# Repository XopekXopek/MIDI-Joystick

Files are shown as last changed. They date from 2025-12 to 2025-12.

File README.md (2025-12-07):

The DIY MIDI Joystick project is a custom-built controller originaly designed for Elektron Monomachine (c).  
Joystick can be used for controlling other hardware and software music instruments, effects, and adding unique motion-based input to any MIDI-compatible setup.

Built around an Arduino microcontroller, the device supports multiple operational modes, channel selection, 
button inputs, and precise analog readings from X/Y joystick axes. 

It communicates through USB or classic 5-pin MIDI DIN input/output and supports MIDI IN → MIDI OUT (thru) forwarding.

Features:

Pitch Bend on X-axis
Split CC control (CC1 + CC2) on Y-axis
MIDI channel selection
Axis swapping (X ↔ Y)
Full calibration system
EEPROM storage settings
MIDI Thru
LED status indication

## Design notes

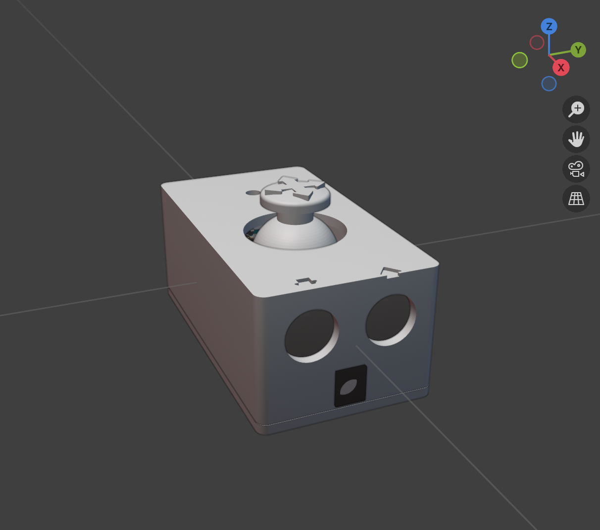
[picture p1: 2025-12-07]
Enclosure/3D overview.png

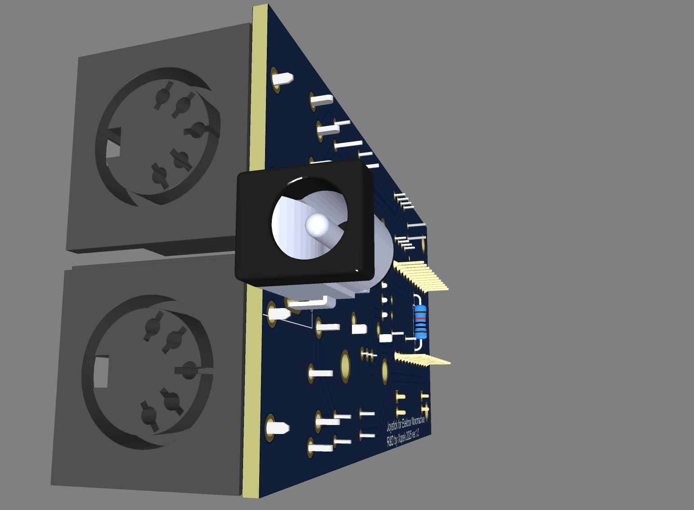
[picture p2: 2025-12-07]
PCB&Schematic/PCB_3.png

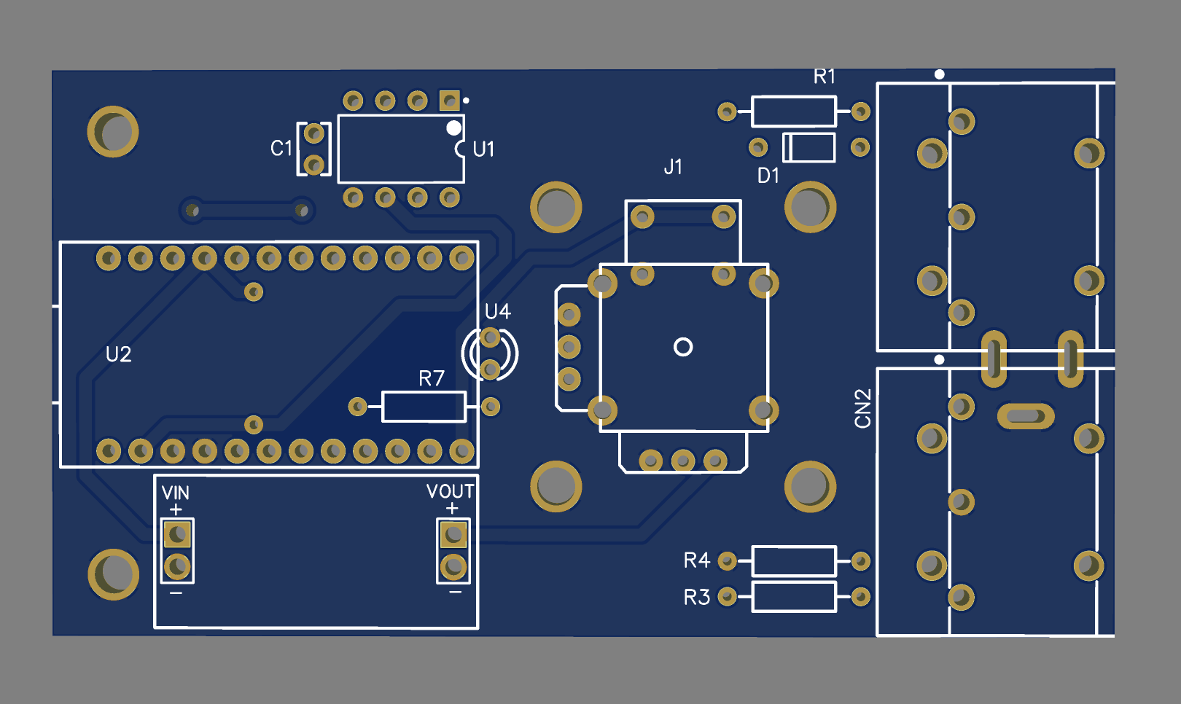
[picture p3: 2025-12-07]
PCB&Schematic/PCB_2.png

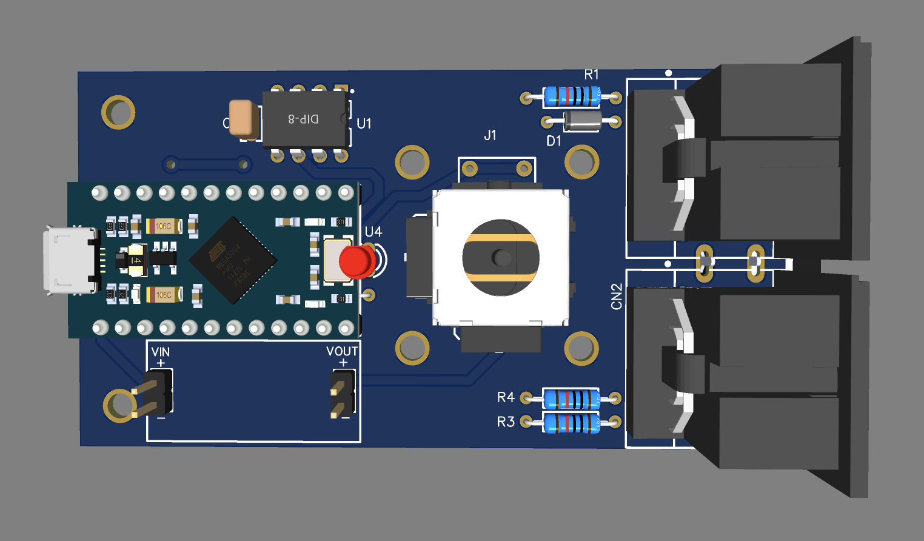
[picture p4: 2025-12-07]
PCB&Schematic/PCB_1.png

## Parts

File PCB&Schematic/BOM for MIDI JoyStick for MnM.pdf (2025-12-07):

BOM for Elektron Monomachine (c) MIDI Joystick ver. 1.0

ID | Name | Designator | Quantity | Manufacturer Part
1 | DIN-5 MIDI INPUT/OUTPUT | CN1, CN2 | 2 | DIN-504-M10
3 | 1N4148 | D1 | 1 | 1N4148
4 | DC Jack socket 5.5 X 2.5 mm | DC1 | 1 | DCS-005
5 | 220R | R1,R3,R4 | 3 | MF 1/4W-220Ω±1%
6 | 1K | R2,R7 | 2 | MF 1/4W-1KΩ±1%
7 | 6N137 | U1 | 1 | HT-6N137
8 | ARDUINO PRO MICRO | U2 | 1 | ARDUINO PRO MICRO (USB C or mcroUSB)
9 | LED | U4 | 1 | 5mm
10 | 100nF | C1 | 1 | Metalfilm Cap
11 | Module YL-46 | VIN,VOUT | 1 | AMS1117 3.3V 5.0V DC-DC Step down Power Supply
12 | Joystick | P1 | 1 | Dualsense PS5/Ginfull with button
13 | DC Y-cable 5.5 X 2.5 mm | - | 1 | DC Y-cable 5.5 X 2.5 mm

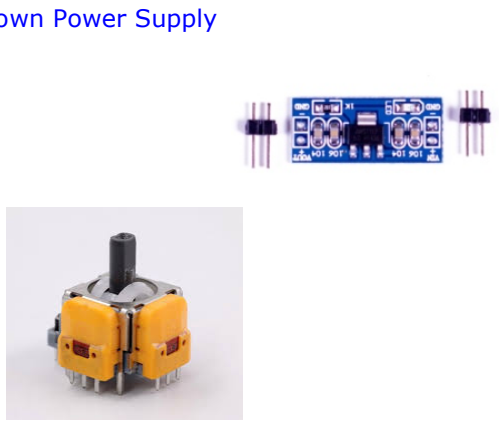
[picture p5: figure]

AMS1117 3.3V 5.0V DC-DC Step down Power Supply

Dualsense PS5/Ginfull with button

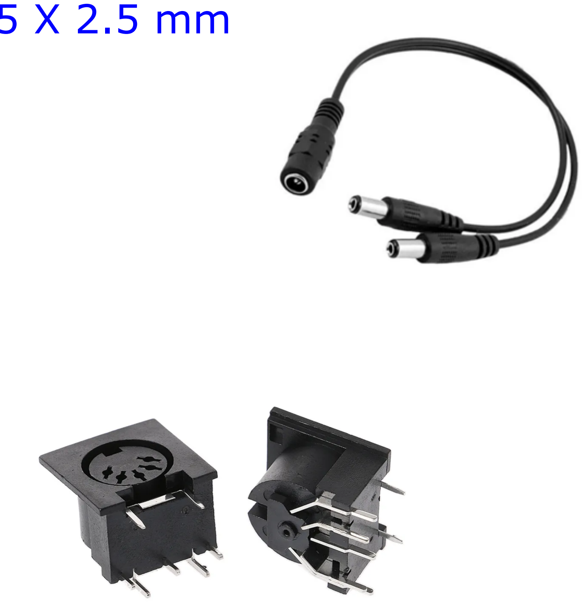
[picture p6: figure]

DC Y-cable 5.5 X 2.5 mm

DIN-504-M10

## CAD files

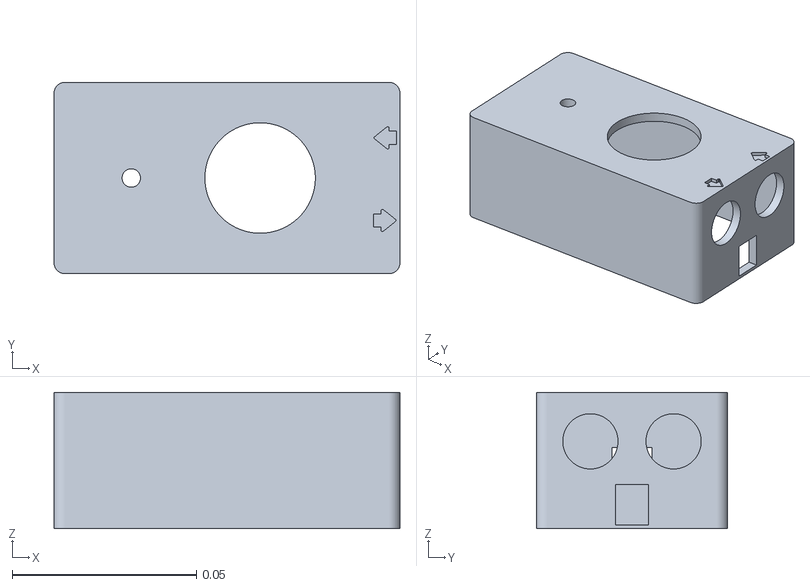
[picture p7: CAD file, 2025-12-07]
Enclosure/Enclosure_main.stl
0.094 x 0.052 x 0.037

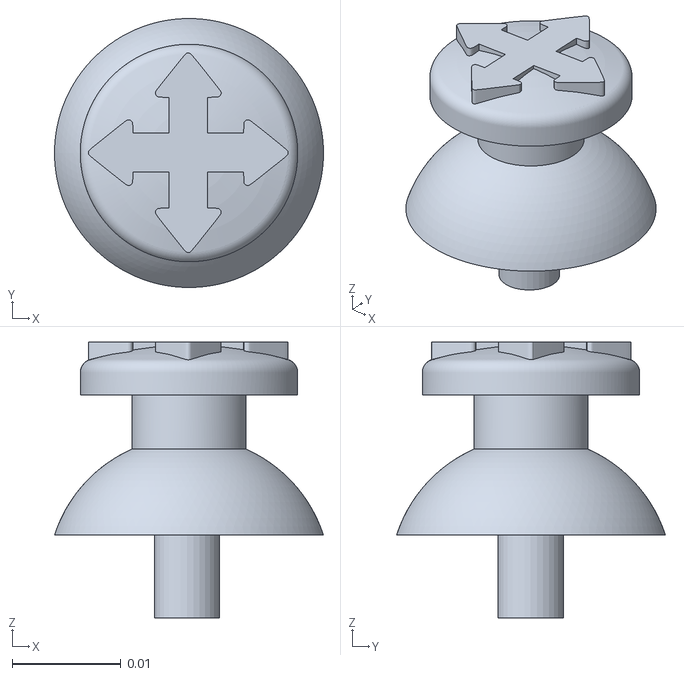
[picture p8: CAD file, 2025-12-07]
Enclosure/Joystick_cap.stl
0.0247 x 0.0247 x 0.0254

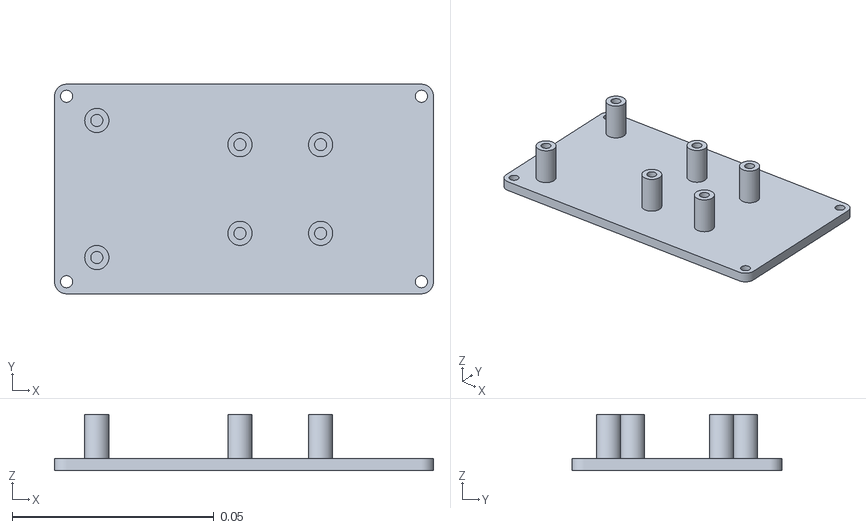
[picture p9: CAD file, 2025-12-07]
Enclosure/bottom_cover.stl
0.094 x 0.052 x 0.014

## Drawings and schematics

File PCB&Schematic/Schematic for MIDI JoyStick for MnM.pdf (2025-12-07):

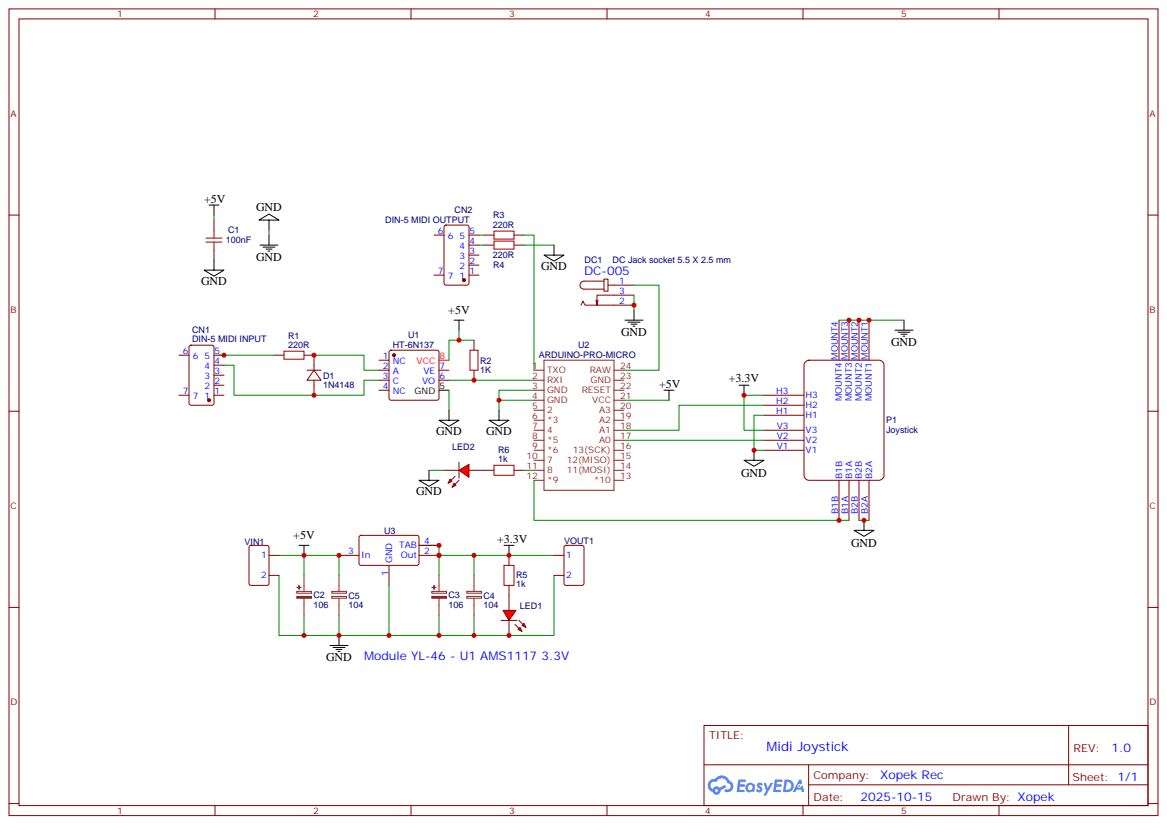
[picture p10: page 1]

DC1 DC Jack socket 5.5 X 2.5 mm

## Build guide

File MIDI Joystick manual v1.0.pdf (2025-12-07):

# 📘 MIDI Joystick – User Manual v.1.0

## ⚙ Overview

This device is a MIDI controller based on an analog joystick and a single button.
It communicates through a classic 5-pin MIDI DIN output and supports MIDI IN → MIDI OUT (thru) forwarding.

Features:

- Pitch Bend on X-axis
- Split CC control (CC1 + CC2) on Y-axis
- MIDI channel selection
- Axis swapping (X ↔ Y)
- Full calibration system
- EEPROM storage
- MIDI Thru
- LED status indication

# 🎮 Joystick Functions

## X-Axis → Pitch Bend

- Left = −8192
- Center = 0
- Right = +8191
- Includes a small deadzone to prevent jitter.

## Y-Axis → Split CC Control (CC1 / CC2)

The Y-axis is divided into two functional halves:

Position | MIDI CC Value Range
Below center (0–63) CC1 | 63 → 0
Above center (65–127) CC2 | 0 → 63

The center point (64) sends no data to avoid unwanted triggering.

# 🔘 Button Functions

The button performs different actions depending on short presses, long presses, and sequences.

## 1⃣Select MIDI Channel (1–16)

Enter MIDI Channel Setup

Hold the button for more than 3 seconds.
The LED blinks 3 times — channel setup mode is active.

Select the channel

Press the button N times:

- 1 press → Channel 1
- 2 presses → Channel 2
- …
- 16 presses → Channel 16

Each press is confirmed by one LED blink.

Confirm the channel

Hold the button for more than 5 seconds.
LED will blink N times — the selected channel. The device returns to normal mode.

## 2⃣ Swap Axes (X ↔ Y)

Perform 5 short presses in a row.
LED blinks 2 times.
Useful if the joystick is mounted sideways or rotated.

## 3⃣ Joystick Calibration Mode

Enter Calibration

Perform 10 short presses in a row.
LED blinks 5 times.

Calibrating

Move the joystick to all edges and corners. The device automatically captures:

- Xmin / Xmax
- Ymin / Ymax

Exit Calibration and Save

Hold the button for more than 5 seconds. LED blinks 3 times — calibration saved.

# 💾 EEPROM Storage

The following parameters are stored permanently:

- Joystick calibration
- MIDI channel
- Axis swap setting

These values remain stored even after powering off.

# 🔌 MIDI IN → MIDI OUT (Thru)

All incoming MIDI DIN messages are automatically forwarded to MIDI OUT:

- Note On / Off
- Control Change
- Pitch Bend
- Channel messages

This allows chaining the joystick controller with other MIDI devices.

# 🔆 LED Indicator Codes

Event | LED Blinks
Enter MIDI channel setup 3
Short press in MIDI setup 1
Confirm MIDI channel | N
Axis swap | 2
Enter calibration | 5
Exit calibration | 3

# 📎 Quick Control Summary

- Hold > 3 sec → MIDI channel setup
- N short presses → Select channel
- Hold > 5 sec → Confirm channel

- 5 short presses → Swap X/Y axes
- 10 short presses → Calibration mode
- Hold > 5 sec (in calibration) → Save calibration

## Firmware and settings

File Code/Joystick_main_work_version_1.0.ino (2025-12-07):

#include <MIDI.h>
#include <EEPROM.h>
#include <elapsedMillis.h>

MIDI_CREATE_DEFAULT_INSTANCE();

enum Mode {
  MODE_PLAY,
  MODE_CHANNEL_SELECT,
  MODE_SENS_SELECT,
  MODE_CALIBRATION
};

Mode currentMode = MODE_PLAY;

const int buttonPin = 2;
const int xPin = A0;
const int yPin = A1;
int midiChannel = 1;
int sensivity = 10;

bool buttonPressed = false;
bool longPress = false;
elapsedMillis buttonTimer;
const unsigned long longPressTime = 600;

int rawCenterX = 512;
int rawCenterY = 512;

int calibrationMinX = 1023;
int calibrationMaxX = 0;
int calibrationMinY = 1023;
int calibrationMaxY = 0;

void saveSettings() {
  EEPROM.update(0, midiChannel);
  EEPROM.update(1, sensivity);
  EEPROM.put(2, rawCenterX);
  EEPROM.put(4, rawCenterY);
}

void loadSettings() {
  midiChannel = EEPROM.read(0);
  sensivity = EEPROM.read(1);
  EEPROM.get(2, rawCenterX);
  EEPROM.get(4, rawCenterY);
  if (midiChannel < 1 || midiChannel > 16) midiChannel = 1;
  if (sensivity < 1 || sensivity > 20) sensivity = 10;
}

void setup() {
  pinMode(buttonPin, INPUT_PULLUP);
  MIDI.begin(MIDI_CHANNEL_OMNI);
  loadSettings();
}

void handleButton() {
  if (!digitalRead(buttonPin)) {
    if (!buttonPressed) {
      buttonPressed = true;
      buttonTimer = 0;
    } else {
      if (buttonTimer > longPressTime && !longPress) {
        longPress = true;
      }
    }
  } else {
    if (buttonPressed) {
      if (longPress) {
        switch (currentMode) {
          case MODE_PLAY:
            currentMode = MODE_CALIBRATION;
            break;
          case MODE_CALIBRATION:
            saveSettings();
            currentMode = MODE_PLAY;
            break;
          default:
            break;
        }
      } else {
        switch (currentMode) {
          case MODE_PLAY:
            currentMode = MODE_CHANNEL_SELECT;
            break;
          case MODE_CHANNEL_SELECT:
            midiChannel++;
            if (midiChannel > 16) midiChannel = 1;
            saveSettings();
            break;
          case MODE_SENS_SELECT:
            sensivity++;
            if (sensivity > 20) sensivity = 1;
            saveSettings();
            break;
          default:
            break;
        }
      }
    }
    buttonPressed = false;
    longPress = false;
  }
}

void handleJoystick() {
  int x = analogRead(xPin);
  int y = analogRead(yPin);
  x = map(x, calibrationMinX, calibrationMaxX, 0, 127);
  y = map(y, calibrationMinY, calibrationMaxY, 0, 127);
  x = constrain(x, 0, 127);
  y = constrain(y, 0, 127);
  MIDI.sendControlChange(1, x, midiChannel);
  MIDI.sendControlChange(2, y, midiChannel);
}

void handleCalibration() {
  int x = analogRead(xPin);
  int y = analogRead(yPin);
  if (x < calibrationMinX) calibrationMinX = x;
  if (x > calibrationMaxX) calibrationMaxX = x;
  if (y < calibrationMinY) calibrationMinY = y;
  if (y > calibrationMaxY) calibrationMaxY = y;
}

void loop() {
  handleButton();
  switch (currentMode) {
    case MODE_PLAY:
      handleJoystick();
      break;
    case MODE_CHANNEL_SELECT:
      break;
    case MODE_SENS_SELECT:
      break;
    case MODE_CALIBRATION:
      handleCalibration();
      break;
  }
}

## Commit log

2025-12-07 Rename BOM for MIDI JoyStick for MnM.pdf to PCB&Schematic/BOM for MIDI JoyStick for MnM.pdf
2025-12-07 Rename Schematic for MIDI JoyStick for MnM.pdf to PCB&Schematic/Schematic for MIDI JoyStick for MnM.pdf
